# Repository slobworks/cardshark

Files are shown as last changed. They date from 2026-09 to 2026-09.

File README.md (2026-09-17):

cardshark_front
cardshark_back png
<b>Update 9/17/26:</b> Big gaggle of minor changes all over. Bigger, better and cleaner PCB art on the front. Changed all those pesky 0603 0.1uF capacitors to 0805 to make them slightly less fiddly. Had to do some moderate rerouting to compensate - hopefully the 40MHz operation is not adversely affected.

CARDSHARK Tiburon v1.1 - MIT-Licensed, Open-Source Cirrus Logic CL-GD543x Based VLB VGA Card

As it says on the package. This VGA card for the VESA Local Bus supports a maximum memory size of 2MB, using traditional multiple-CAS FPM 256Kx16 SOJ memory. 70ns or faster memory is recommended, as is a CL-GD5434 chip for the fastest speed and least confusing build.
Created using KiCAD 8.0, updated for 10.0 (a thousand apologies if this breaks your older version!)

Features:
- Four layer PCB with cautiously laid ground pours, and judicious usage of stitching vias
- Beefy dedicated regulator providing analog DAC power, for further improved picture quality
- 2MB FPM memory with 64-bit data bus for CL-GD5434
- Compatible with CL-GD5430 and CL-GD5434
- Uses a 27C256-compatible UV PROM or EPROM chip for the BIOS
- Supports 40MHz VLB bus on motherboards that can actually handle that
- Mercifully short mode-switch delays on LCD monitors, unlike most vintage VGA chipsets (a Cirrus quality)
- Features my own hand-drawn artwork on back of board

Release History:
- Tiburon v1.1: Tons o' minor tweaks: bigger, better and cleaner PCB art on the front. Moved BIOS socket so I can reduce the ominous kink in the RGB traces. More forgiving 0805(2012 metric) footprints for the 0.1uF capacitors; you can still fit 0603s to them though. Moved some stuff around to try to get shorter ground loop paths when possible.
- Tiburon v1.0: First proper release.
- Tiburon Take 3 (internal): FINALLY we have a properly working VLB card... so long as you only use a GD5434 and 2MB of memory. One of the RAS lines got screwed, which gets overridden anyway when a GD5434 is used. Also some really minor bugs (wrong resistor values in a couple spots, easily fixed). At least it sure looks nice assembled, and so long as it's given a GD5434 with 2MB, it's a monster (of the good kind).
- Take 2 (internal): Almost worked. Major bugs all over the place. Barely functional.
- 0.1b: Major overhaul. Relaid everything, redid a lot of stuff that was broken and didn't work (if the previous version wasted your money... sorry! I feel like a prize horse's arse for uploading something so broken, as it is!)

Known Issues:
- Hand-soldering that PQFP-208 chip with all those thin little pins is a nightmare, even with hot air
- While generally very good, Mode 13h and EGA image quality isn't 100% perfect on LCD. Some extremely faint vertical lines, though generally much less pronounced than on extant cards; you will probably want to play with your RetroTINK's timings a bit (these seem to be timing related and not noise, as they are not visible at all in SVGA modes)
- EDO is ONLY supported on CL-GD5434-J-QC, but even then it does not improve performance at all. *NO* other versions support EDO, so don't waste money ordering EDO SOJ chips

Bill of Materials: (All passive parts are 0805/2012 metric unless otherwise indicated)
- 1x Cirrus Logic CL-GD5430 or CL-GD5434 PQFP-208 chip (watch out for fakes - they're everywhere)
- 1x SOIC-14 (3.9mm x 8.7mm P1.27mm) SN74F260DR or directly compatible part
- At least 2x, but up to 4x 256Kx16 dual-CAS Fast Page Mode (*NOT* EDO) SOJ-40 DRAM memory
- 1x 78M05 5V DPAK regulator (LF50 is compatible)
- 1x 14.318MHz DIP-14 CXO 4-pin through-hole oscillator
- 1x MMBT3904 SOT-23 NPN transistor
- 1x TL431DBZ SOT-23 programmable shunt reference
- 3x 11 ohm @ 100MHz ferrite beads (for RGB signals)
- 3x 100+ ohm @ 100MHz ferrite beads (for power rails)
- 2x 1x2 2.54mm THT pin headers + jumper caps
- 1x 2x3 1.27mm SMD pin header + jumper caps
- 4x 10pF 25/50v MLCC X5R/X7R ceramic capacitor
- 20x 0805(2012 metric) 0.1uF 25/50v MLCC X5R/X7R ceramic capacitor
- 4x 2.2uF 25/50v MLCC X5R/X7R ceramic capacitor
- 6x 10uF 25/50v MLCC X5R/X7R ceramic capacitor
- 1x 5mm 22uF 16V SMD electrolytic capacitor
- 1x 0 ohm SMD resistor (or a short snip of wire)
- 3x 0603(1608 metric) 10 ohm SMD resistors
- 1x 4x0603 33 ohm convex SMD resistor pack
- 2x 0603(1608 metric) 75 ohm SMD resistors
- 1x 4x0603 75 ohm convex SMD resistor pack
- 1x 100 ohm SMD resistor
- 3x 0603(1608 metric) 6.8K SMD resistors
- 2x 4x0603 6.8K ohm convex SMD resistor packs
- 1x 0603(1608 metric) 270-330 ohm SMD resistor, 1% thin film
- 2x 1K SMD resistors
- 1x DSUB-15-HD right angle through hole VGA connector (something akin to this: https://www.digikey.com/en/products/detail/assmann-wsw-components/A-HDF15A-KG-TAXB/1241905)
- 1x DIP-28 socket + 27C256 or compatible PROM/EEPROM/flash ROM chip for BIOS + BIOS file (figure that out yourself)

Provided under the terms of the MIT License.

As you can see I'm a bit of a neophyte when it comes to this GitHub stuff.
Expect this to change as I become more familiar with the platform.

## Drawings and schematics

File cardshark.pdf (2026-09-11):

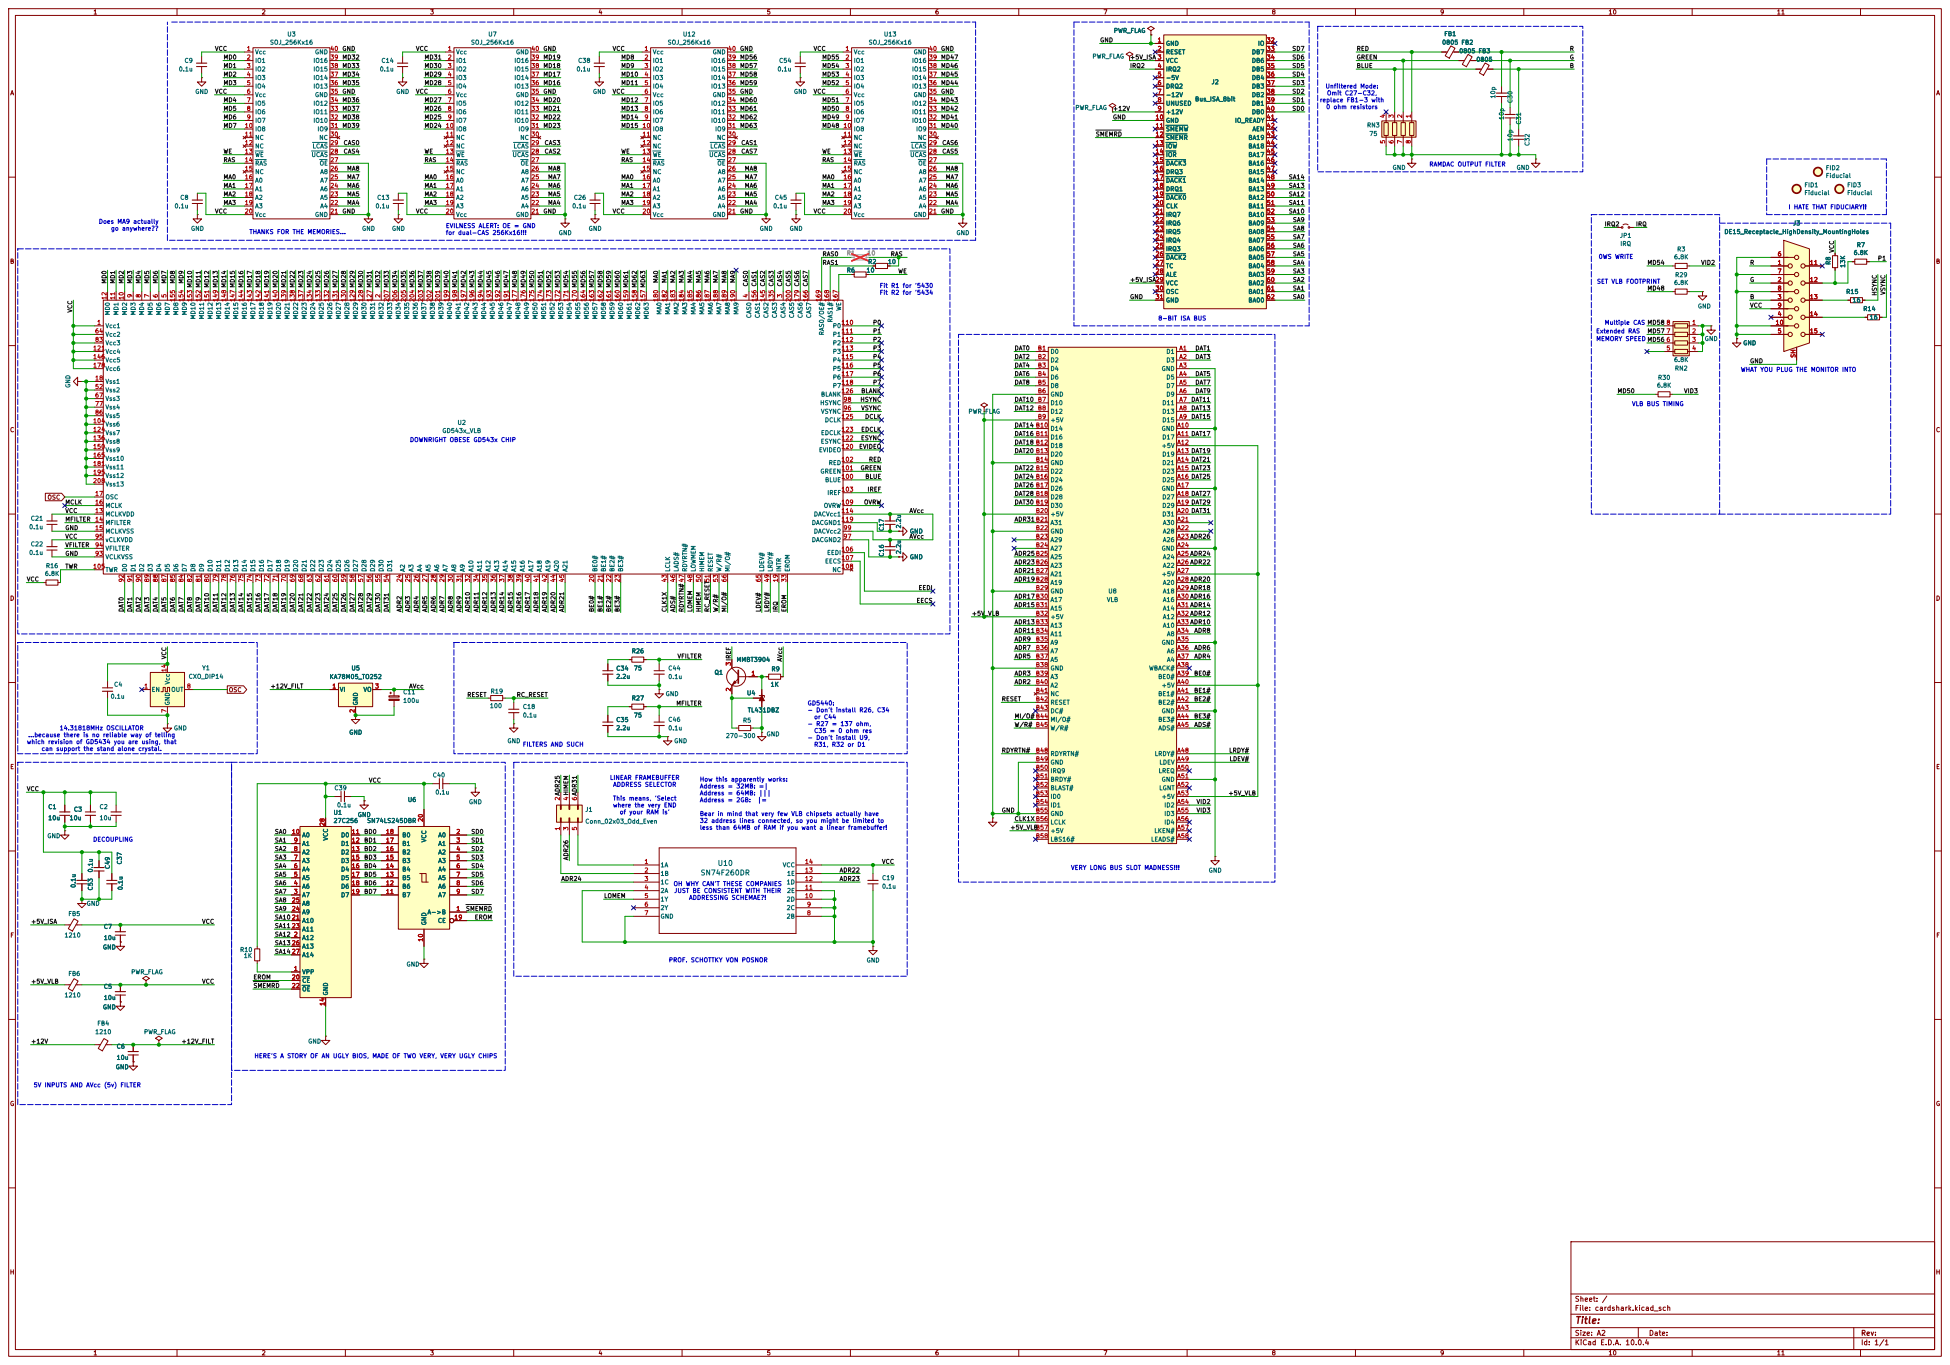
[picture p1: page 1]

PWR_FLAG

VCC
IO8 10 NC 11 NC 12 WE 13 RAS 14 NC 15

J3 DE15_Receptacle_HighDensity_MountingHoles GND

replace FB1-3 with 0 ohm resistors

EVILNESS ALERT: OE = GND
+12V_FILT MD0 +5V_VLB

9 MD2 10 MD1 11 MD0 12 MCLKVDD 13 MFILTER 14 MCLKVSS 15 MCLK 16 OSC 17

3 CAS0
EECS107 NC108 OVRW109 P0110 P1111 P2112 P3113 DACVcc1114 P4115 P5116 P6117 P7118 DACGND1119
Multiple CAS GD5440: - Don't install R26, C34 or C44 - R27 = 137 ohm, C35 = 0 ohm res - Don't install U9,

WHAT YOU PLUG THE MONITOR INTO

A2 B40 NC B41 RESET B42 DC# B43 MI/O# B44 W/R# B45 RDYRTN# B48 GND B49

GND
of your RAM is' FILTERS AND SUCH

ADDRESSING SCHEMAE?! How this apparently works: Address = 32MB: =| Address = 64MB:

This means, 'Select where the very END

Bear in mind that very few VLB chipsets actually have 32 address lines connected, so you might be limited to

less than 64MB of RAM if you want a linear framebuffer!

VERY LONG BUS SLOT MADNESS!!! HERE'S A STORY OF AN UGLY BIOS, MADE OF TWO VERY, VERY UGLY CHIPS

OH WHY CAN'T THESE COMPANIES
JUST BE CONSISTENT WITH THEIR

PROF. SCHOTTKY VON POSNOR

5V INPUTS AND AVcc (5v) FILTER

Size: A2 | Rev:
KiCad E.D.A. 10.0.4 | Id: 1/1

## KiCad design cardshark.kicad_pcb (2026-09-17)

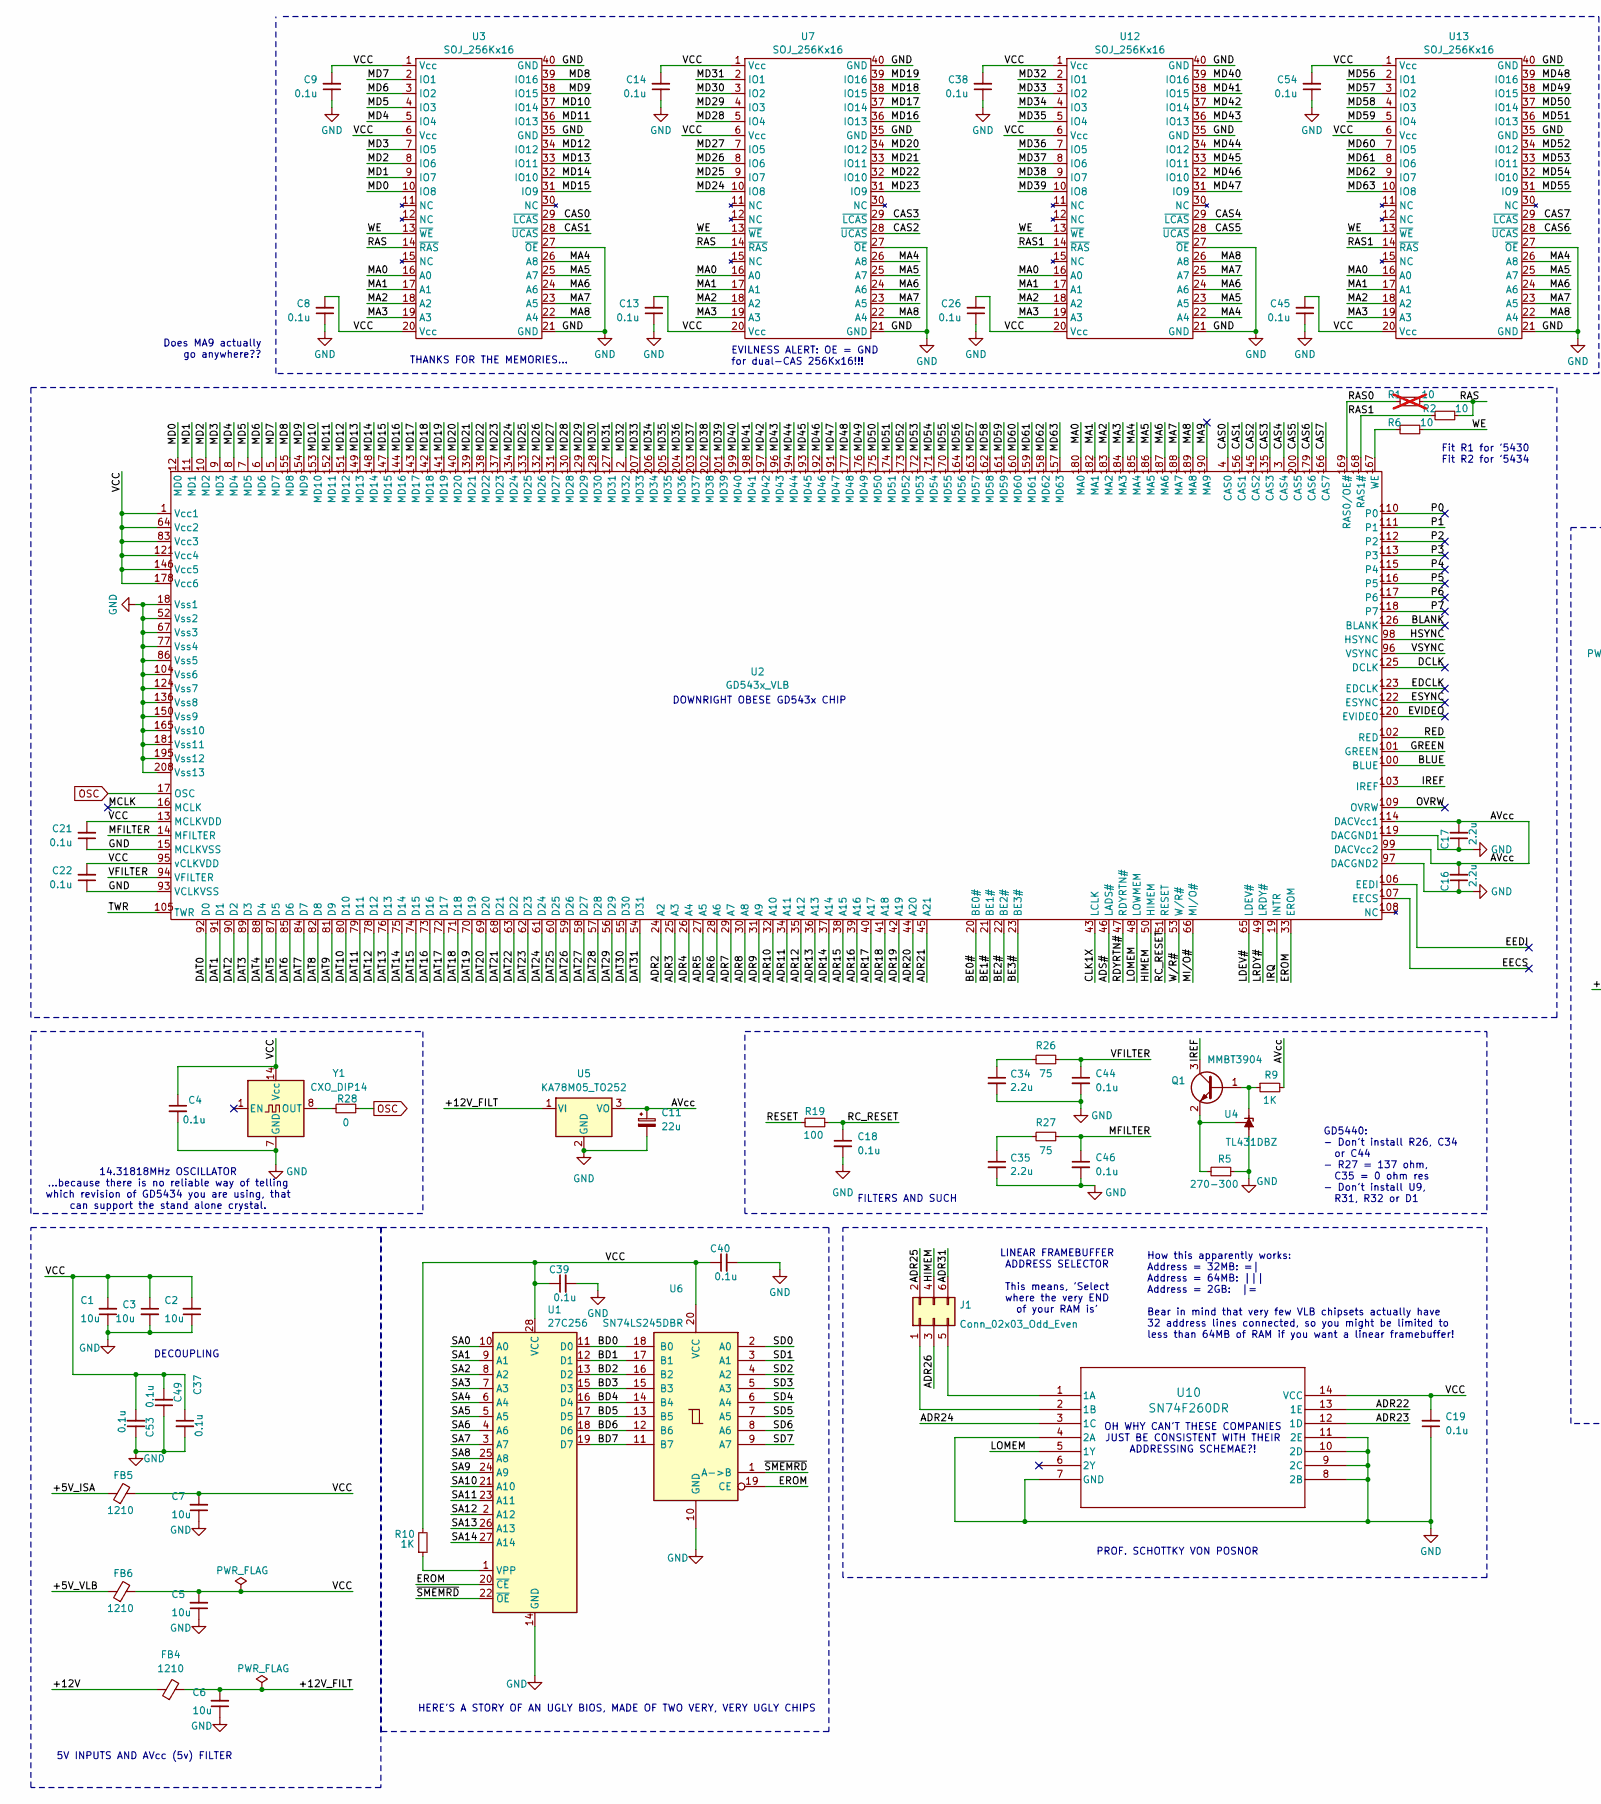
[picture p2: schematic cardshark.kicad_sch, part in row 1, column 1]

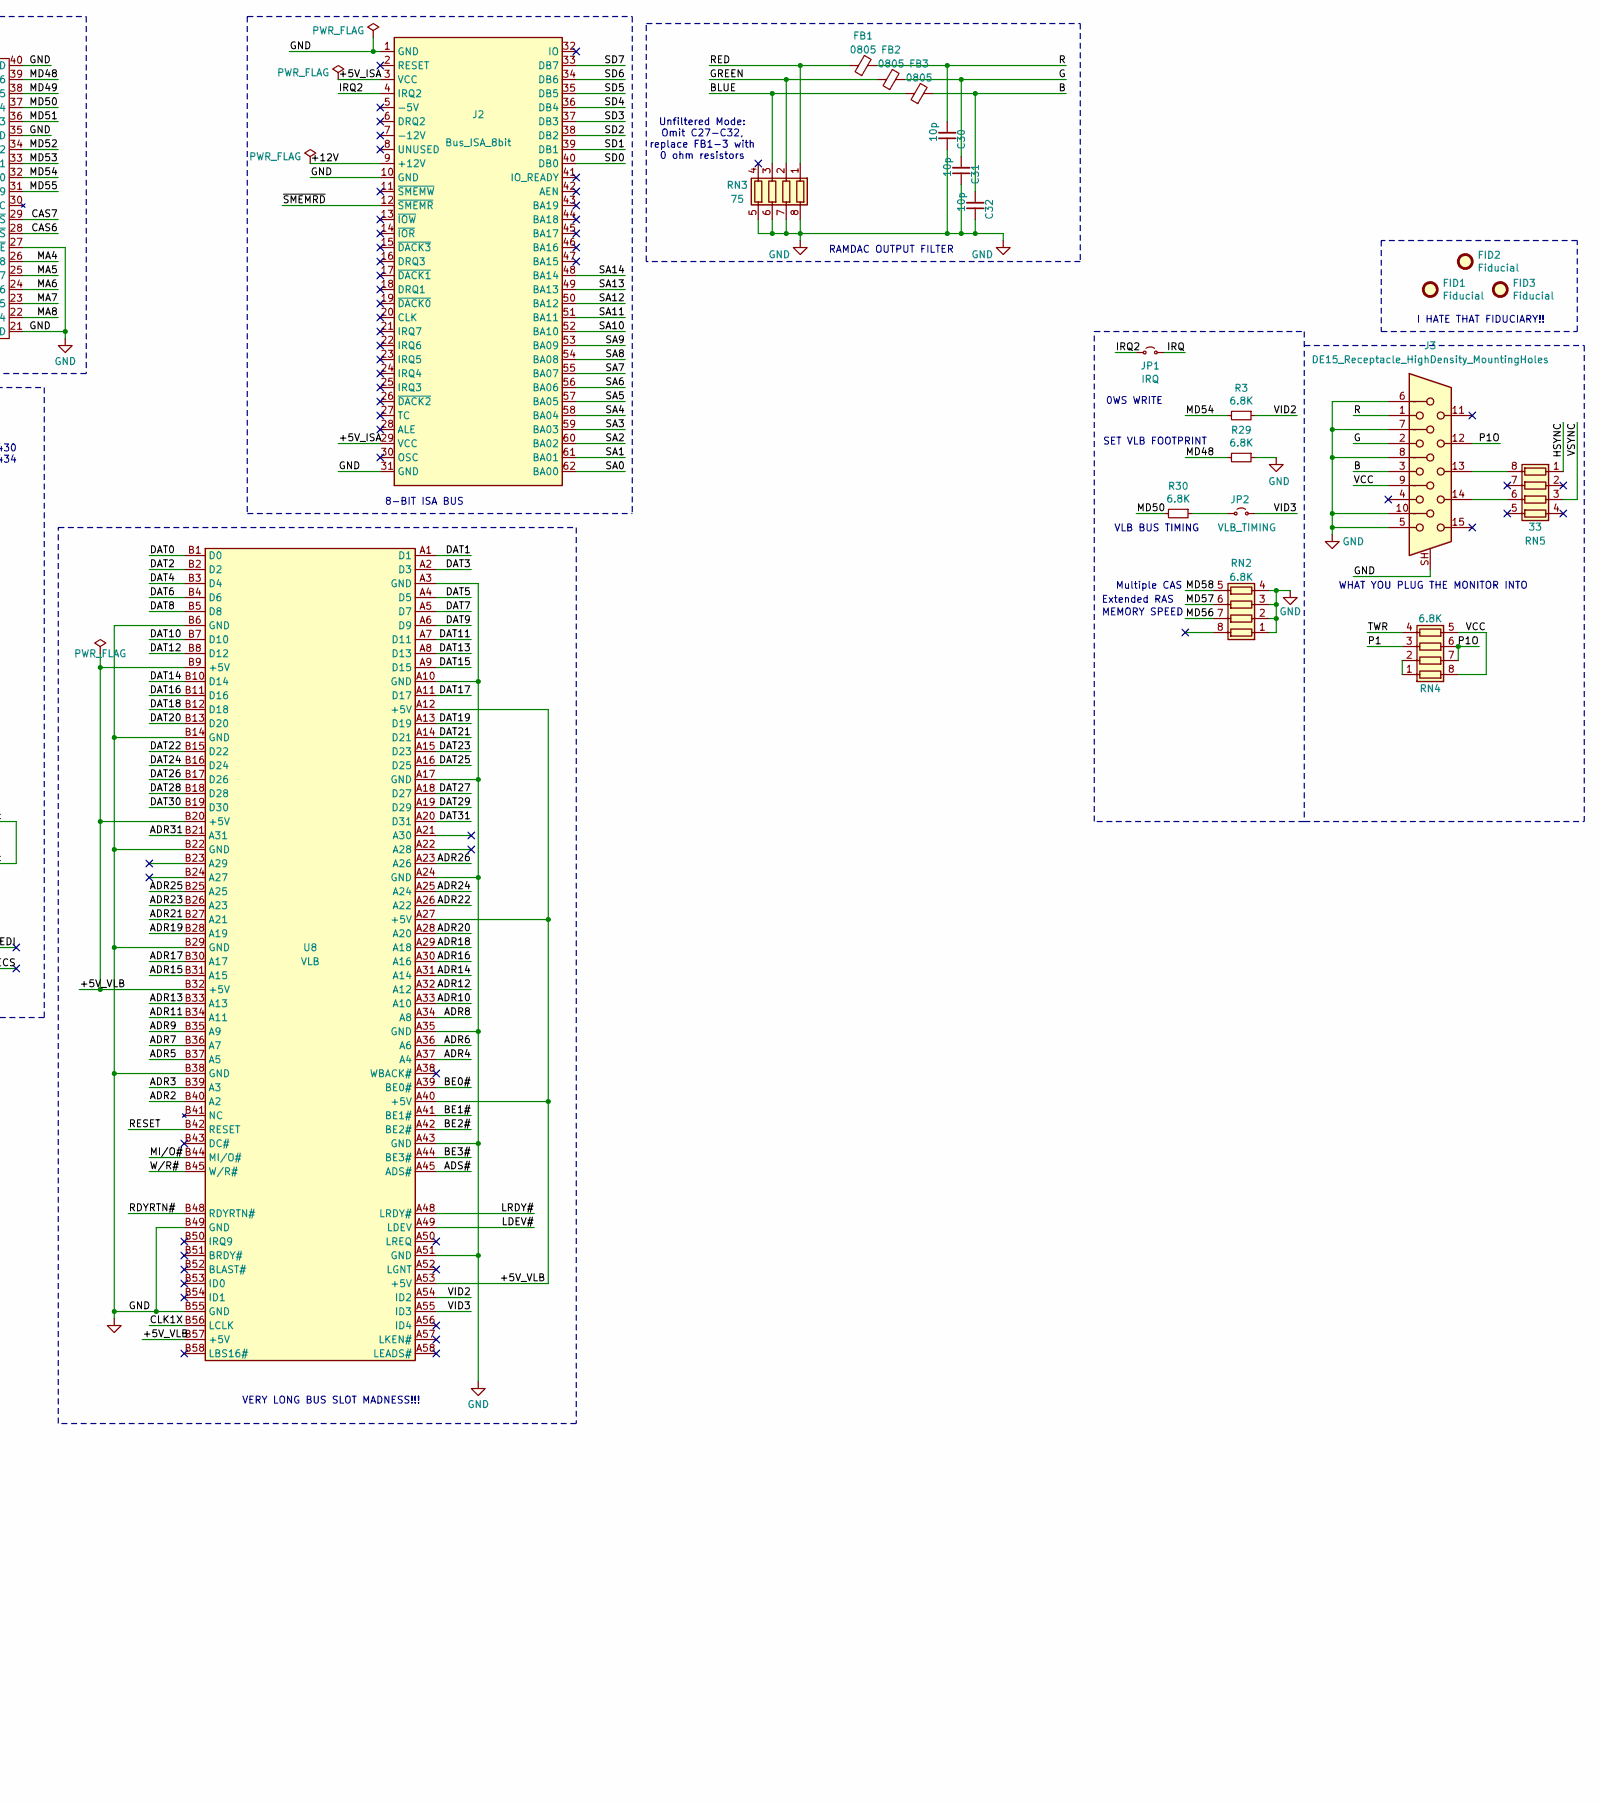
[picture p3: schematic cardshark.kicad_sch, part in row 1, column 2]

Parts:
C1, C2, C3, C5, C6, C7: 10u; C_0805_2012Metric
C4, C8, C9, C13, C14, C18, C19, C21, C22, C26, C37, C38, C39, C40, C44, C45, C46, C49, C53, C54: 0.1u; C_0805_2012Metric
C11: 22u; CP_Elec_5x5.9
C16, C17, C34, C35: 2.2u; C_0805_2012Metric
C30, C31, C32: 10p; C_0805_2012Metric
FB1, FB2, FB3: 0805; L_0805_2012Metric
FB4, FB5, FB6: 1210; L_0805_2012Metric
FID1, FID2, FID3: Fiducial; Fiducial_1mm_Mask2mm
J1: Conn_02x03_Odd_Even; PinHeader_2x03_P1.27mm_Vertical_SMD
J2: Bus_ISA_8bit; ISA
J3: DE15_Receptacle_HighDensity_MountingHoles; DSUB-15-HD
JP1: IRQ; PinHeader_1x02_P2.54mm_Vertical
JP2: VLB_TIMING; PinHeader_1x02_P2.54mm_Vertical
Q1: MMBT3904; SOT-23
R1: 10; R_0603_1608Metric; not fitted
R2, R6: 10; R_0603_1608Metric
R3, R29, R30: 6.8K; R_0603_1608Metric
R5: 270-300; R_0805_2012Metric
R9, R10: 1K; R_0805_2012Metric
R19: 100; R_0805_2012Metric
R26, R27: 75; R_0805_2012Metric
R28: 0; R_0805_2012Metric
RN2, RN4: 6.8K; ResArray_Convex_4x0603
RN3: 75; ResArray_Convex_4x0603
RN5: 33; ResArray_Convex_4x0603
U1: 27C256; DIP-28_W15.24mm_Socket
U2: GD543x_VLB; PQFP-208_28x28mm_P0.5mm
U3, U7, U12, U13: SOJ_256Kx16; SOJ-40_10.16x26.44mm_P1.27mm
U4: TL431DBZ; SOT-23
U5: KA78M05_TO252; TO-252-2
U6: SN74LS245DBR; SSOP-20_5.3x7.2mm_P0.65mm
U8: VLB
U10: SN74F260DR; SOIC-14_3.9x8.7mm_P1.27mm
Y1: CXO_DIP14; Oscillator_SMD_DIP-14

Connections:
/+5V_ISA: FB5.1, J2.3 (VCC), J2.29 (VCC)
/+5V_VLB: FB6.1, U8.A12 (+5V), U8.A27 (+5V), U8.A40 (+5V), U8.A53 (+5V), U8.B9 (+5V), U8.B20 (+5V), U8.B32 (+5V), U8.B57 (+5V)
/+12V: FB4.1, J2.9 (+12V)
/+12V_FILT: C6.2, FB4.2, U5.1 (VI)
/ADR2: U2.24 (A2), U8.B40 (A2)
/ADR3: U2.25 (A3), U8.B39 (A3)
/ADR4: U2.26 (A4), U8.A37 (A4)
/ADR5: U2.27 (A5), U8.B37 (A5)
/ADR6: U2.28 (A6), U8.A36 (A6)
/ADR7: U2.29 (A7), U8.B36 (A7)
/ADR8: U2.30 (A8), U8.A34 (A8)
/ADR9: U2.31 (A9), U8.B35 (A9)
/ADR10: U2.32 (A10), U8.A33 (A10)
/ADR11: U2.34 (A11), U8.B34 (A11)
/ADR12: U2.35 (A12), U8.A32 (A12)
/ADR13: U2.36 (A13), U8.B33 (A13)
/ADR14: U2.37 (A14), U8.A31 (A14)
/ADR15: U2.38 (A15), U8.B31 (A15)
/ADR16: U2.39 (A16), U8.A30 (A16)
/ADR17: U2.40 (A17), U8.B30 (A17)
/ADR18: U2.41 (A18), U8.A29 (A18)
/ADR19: U2.42 (A19), U8.B28 (A19)
/ADR20: U2.44 (A20), U8.A28 (A20)
/ADR21: U2.45 (A21), U8.B27 (A21)
/ADR22: U8.A26 (A22), U10.13 (1E)
/ADR23: U8.B26 (A23), U10.12 (1D)
/ADR24: U8.A25 (A24), U10.3 (1C)
/ADR25: J1.2, U8.B25 (A25)
/ADR26: J1.3, U8.A23 (A26)
/ADR31: J1.6, U8.B21 (A31)
/ADS#: U2.46 (LADS#), U8.A45 (ADS#)
/AVcc: C11.1, C16.2, C17.2, R9.2, U2.99 (DACVcc2), U2.114 (DACVcc1), U5.3 (VO)
/B: C32.2, FB3.2, J3.3
/BD0: U1.11 (D0), U6.18 (B0)
/BD1: U1.12 (D1), U6.17 (B1)
/BD2: U1.13 (D2), U6.16 (B2)
/BD3: U1.15 (D3), U6.15 (B3)
/BD4: U1.16 (D4), U6.14 (B4)
/BD5: U1.17 (D5), U6.13 (B5)
/BD6: U1.18 (D6), U6.12 (B6)
/BD7: U1.19 (D7), U6.11 (B7)
/BE0#: U2.20 (BE0#), U8.A39 (BE0#)
/BE1#: U2.21 (BE1#), U8.A41 (BE1#)
/BE2#: U2.22 (BE2#), U8.A42 (BE2#)
/BE3#: U2.23 (BE3#), U8.A44 (BE3#)
/BLANK: U2.126 (BLANK)
/BLUE: FB3.1, RN3.3 (R3.1), U2.100 (BLUE)
/CAS0: U2.4 (CAS0), U3.29 (~LCAS)
/CAS1: U2.156 (CAS1), U3.28 (~UCAS)
/CAS2: U2.145 (CAS2), U7.28 (~UCAS)
/CAS3: U2.135 (CAS3), U7.29 (~LCAS)
/CAS4: U2.3 (CAS4), U12.29 (~LCAS)
/CAS5: U2.200 (CAS5), U12.28 (~UCAS)
/CAS6: U2.179 (CAS6), U13.28 (~UCAS)
/CAS7: U2.166 (CAS7), U13.29 (~LCAS)
/CLK1X: U2.43 (LCLK), U8.B56 (LCLK)
/DAT0: U2.92 (D0), U8.B1 (D0)
/DAT1: U2.91 (D1), U8.A1 (D1)
/DAT2: U2.90 (D2), U8.B2 (D2)
/DAT3: U2.89 (D3), U8.A2 (D3)
/DAT4: U2.88 (D4), U8.B3 (D4)
/DAT5: U2.87 (D5), U8.A4 (D5)
/DAT6: U2.85 (D6), U8.B4 (D6)
/DAT7: U2.84 (D7), U8.A5 (D7)
/DAT8: U2.82 (D8), U8.B5 (D8)
/DAT9: U2.81 (D9), U8.A6 (D9)
/DAT10: U2.80 (D10), U8.B7 (D10)
/DAT11: U2.79 (D11), U8.A7 (D11)
/DAT12: U2.78 (D12), U8.B8 (D12)
/DAT13: U2.76 (D13), U8.A8 (D13)
/DAT14: U2.75 (D14), U8.B10 (D14)
/DAT15: U2.74 (D15), U8.A9 (D15)
/DAT16: U2.73 (D16), U8.B11 (D16)
/DAT17: U2.72 (D17), U8.A11 (D17)
/DAT18: U2.71 (D18), U8.B12 (D18)
/DAT19: U2.70 (D19), U8.A13 (D19)
/DAT20: U2.69 (D20), U8.B13 (D20)
/DAT21: U2.68 (D21), U8.A14 (D21)
/DAT22: U2.63 (D22), U8.B15 (D22)
/DAT23: U2.62 (D23), U8.A15 (D23)
/DAT24: U2.61 (D24), U8.B16 (D24)
/DAT25: U2.60 (D25), U8.A16 (D25)
/DAT26: U2.59 (D26), U8.B17 (D26)
/DAT27: U2.58 (D27), U8.A18 (D27)
/DAT28: U2.57 (D28), U8.B18 (D28)
/DAT29: U2.56 (D29), U8.A19 (D29)
/DAT30: U2.55 (D30), U8.B19 (D30)
/DAT31: U2.54 (D31), U8.A20 (D31)
/DCLK: U2.125 (DCLK)
/EDCLK: U2.123 (EDCLK)
/EECS: U2.107 (EECS)
/EEDI: U2.106 (EEDI)
/EROM: U1.20 (~CE), U2.33 (EROM), U6.19 (CE)
/ESYNC: U2.122 (ESYNC)
/EVIDEO: U2.120 (EVIDEO)
/G: C31.2, FB2.2, J3.2
/GREEN: FB2.1, RN3.2 (R2.1), U2.101 (GREEN)
/HIMEM: J1.4, U2.50 (HIMEM)
/HSYNC: RN5.1 (R1.1), U2.98 (HSYNC)
/IREF: Q1.3 (C), U2.103 (IREF)
/IRQ: JP1.2 (B), U2.19 (INTR)
/IRQ2: J2.4 (IRQ2), JP1.1 (A)
/LDEV#: U2.65 (LDEV#), U8.A49 (LDEV)
/LOMEM: U2.48 (LOWMEM), U10.5 (1Y)
/LRDY#: U2.49 (LRDY#), U8.A48 (LRDY#)
/MA0: U2.180 (MA0), U3.16 (A0), U7.16 (A0), U12.16 (A0), U13.16 (A0)
/MA1: U2.182 (MA1), U3.17 (A1), U7.17 (A1), U12.17 (A1), U13.17 (A1)
/MA2: U2.183 (MA2), U3.18 (A2), U7.18 (A2), U12.18 (A2), U13.18 (A2)
/MA3: U2.184 (MA3), U3.19 (A3), U7.19 (A3), U12.19 (A3), U13.19 (A3)
/MA4: U2.185 (MA4), U3.26 (A8), U7.26 (A8), U12.22 (A4), U13.26 (A8)
/MA5: U2.186 (MA5), U3.25 (A7), U7.25 (A7), U12.23 (A5), U13.25 (A7)
/MA6: U2.187 (MA6), U3.24 (A6), U7.24 (A6), U12.24 (A6), U13.24 (A6)
/MA7: U2.188 (MA7), U3.23 (A5), U7.23 (A5), U12.25 (A7), U13.23 (A5)
/MA8: U2.189 (MA8), U3.22 (A4), U7.22 (A4), U12.26 (A8), U13.22 (A4)
/MA9: U2.190 (MA9)
/MCLK: U2.16 (MCLK)
/MD0: U2.12 (MD0), U3.10 (IO8)
/MD1: U2.11 (MD1), U3.9 (IO7)
/MD2: U2.10 (MD2), U3.8 (IO6)
/MD3: U2.9 (MD3), U3.7 (IO5)
/MD4: U2.8 (MD4), U3.5 (IO4)
/MD5: U2.7 (MD5), U3.4 (IO3)
/MD6: U2.6 (MD6), U3.3 (IO2)
/MD7: U2.5 (MD7), U3.2 (IO1)
/MD8: U2.155 (MD8), U3.39 (IO16)
/MD9: U2.154 (MD9), U3.38 (IO15)
/MD10: U2.153 (MD10), U3.37 (IO14)
/MD11: U2.152 (MD11), U3.36 (IO13)
/MD12: U2.151 (MD12), U3.34 (IO12)
/MD13: U2.149 (MD13), U3.33 (IO11)
/MD14: U2.148 (MD14), U3.32 (IO10)
/MD15: U2.147 (MD15), U3.31 (IO9)
/MD16: U2.144 (MD16), U7.36 (IO13)
/MD17: U2.143 (MD17), U7.37 (IO14)
/MD18: U2.142 (MD18), U7.38 (IO15)
/MD19: U2.141 (MD19), U7.39 (IO16)
/MD20: U2.140 (MD20), U7.34 (IO12)
/MD21: U2.139 (MD21), U7.33 (IO11)
/MD22: U2.138 (MD22), U7.32 (IO10)
/MD23: U2.137 (MD23), U7.31 (IO9)
/MD24: U2.134 (MD24), U7.10 (IO8)
/MD25: U2.133 (MD25), U7.9 (IO7)
/MD26: U2.132 (MD26), U7.8 (IO6)
/MD27: U2.131 (MD27), U7.7 (IO5)
/MD28: U2.130 (MD28), U7.5 (IO4)
/MD29: U2.129 (MD29), U7.4 (IO3)
/MD30: U2.128 (MD30), U7.3 (IO2)
/MD31: U2.127 (MD31), U7.2 (IO1)
/MD32: U2.2 (MD32), U12.2 (IO1)
/MD33: U2.207 (MD33), U12.3 (IO2)
/MD34: U2.206 (MD34), U12.4 (IO3)
/MD35: U2.205 (MD35), U12.5 (IO4)
/MD36: U2.204 (MD36), U12.7 (IO5)
/MD37: U2.203 (MD37), U12.8 (IO6)
/MD38: U2.202 (MD38), U12.9 (IO7)
/MD39: U2.201 (MD39), U12.10 (IO8)
/MD40: U2.199 (MD40), U12.39 (IO16)
/MD41: U2.198 (MD41), U12.38 (IO15)
/MD42: U2.197 (MD42), U12.37 (IO14)
/MD43: U2.196 (MD43), U12.36 (IO13)
/MD44: U2.194 (MD44), U12.34 (IO12)
/MD45: U2.193 (MD45), U12.33 (IO11)
/MD46: U2.192 (MD46), U12.32 (IO10)
/MD47: U2.191 (MD47), U12.31 (IO9)
/MD48: R29.2, U2.177 (MD48), U13.39 (IO16)
/MD49: U2.176 (MD49), U13.38 (IO15)
/MD50: R30.2, U2.175 (MD50), U13.37 (IO14)
/MD51: U2.174 (MD51), U13.36 (IO13)
/MD52: U2.173 (MD52), U13.34 (IO12)
/MD53: U2.172 (MD53), U13.33 (IO11)
/MD54: R3.2, U2.171 (MD54), U13.32 (IO10)
/MD55: U2.170 (MD55), U13.31 (IO9)
/MD56: RN2.7 (R2.2), U2.164 (MD56), U13.2 (IO1)
/MD57: RN2.6 (R3.2), U2.163 (MD57), U13.3 (IO2)
/MD58: RN2.5 (R4.2), U2.162 (MD58), U13.4 (IO3)
/MD59: U2.161 (MD59), U13.5 (IO4)
/MD60: U2.160 (MD60), U13.7 (IO5)
/MD61: U2.159 (MD61), U13.8 (IO6)
/MD62: U2.158 (MD62), U13.9 (IO7)
/MD63: U2.157 (MD63), U13.10 (IO8)
/MFILTER: C46.1, R27.1, U2.14 (MFILTER)
/MI/O#: U2.66 (MI/O#), U8.B44 (MI/O#)
/OVRW: U2.109 (OVRW)
/P0: U2.110 (P0)
/P1: RN4.3 (R3.1), U2.111 (P1)
/P1O: J3.12, RN4.6 (R3.2), RN4.7 (R2.2)
/P2: U2.112 (P2)
/P3: U2.113 (P3)
/P4: U2.115 (P4)
/P5: U2.116 (P5)
/P6: U2.117 (P6)
/P7: U2.118 (P7)
/R: C30.2, FB1.2, J3.1
/RAS: R1.1, R2.1, U3.14 (~RAS), U7.14 (~RAS)
/RAS0: R1.2, U2.169 (RAS0/OE#)
/RAS1: R2.2, U2.168 (RAS1#), U12.14 (~RAS), U13.14 (~RAS)
/RC_RESET: C18.1, R19.1, U2.51 (RESET)
/RDYRTN#: U2.47 (RDYRTN#), U8.B48 (RDYRTN#)
/RED: FB1.1, RN3.1 (R1.1), U2.102 (RED)
/RESET: R19.2, U8.B42 (RESET)
/SA0: J2.62 (BA00), U1.10 (A0)
/SA1: J2.61 (BA01), U1.9 (A1)
/SA2: J2.60 (BA02), U1.8 (A2)
/SA3: J2.59 (BA03), U1.7 (A3)
/SA4: J2.58 (BA04), U1.6 (A4)
/SA5: J2.57 (BA05), U1.5 (A5)
/SA6: J2.56 (BA06), U1.4 (A6)
/SA7: J2.55 (BA07), U1.3 (A7)
/SA8: J2.54 (BA08), U1.25 (A8)
/SA9: J2.53 (BA09), U1.24 (A9)
/SA10: J2.52 (BA10), U1.21 (A10)
/SA11: J2.51 (BA11), U1.23 (A11)
/SA12: J2.50 (BA12), U1.2 (A12)
/SA13: J2.49 (BA13), U1.26 (A13)
/SA14: J2.48 (BA14), U1.27 (A14)
/SD0: J2.40 (DB0), U6.2 (A0)
/SD1: J2.39 (DB1), U6.3 (A1)
/SD2: J2.38 (DB2), U6.4 (A2)
/SD3: J2.37 (DB3), U6.5 (A3)
/SD4: J2.36 (DB4), U6.6 (A4)
/SD5: J2.35 (DB5), U6.7 (A5)
/SD6: J2.34 (DB6), U6.8 (A6)
/SD7: J2.33 (DB7), U6.9 (A7)
/TWR: RN4.4 (R4.1), U2.105 (TWR)
/VCC: C1.2, C2.2, C3.1, C4.1, C5.2, C7.2, C8.2, C9.2, C13.2, C14.2, C19.2, C21.2, C22.2, C26.2, C37.1, C38.2, C39.1, C40.1, C45.2, C49.2, C53.2, C54.2, FB5.2, FB6.2, J3.9, R10.2, RN4.5 (R4.2), RN4.8 (R1.2), U1.28 (VCC), U2.1 (Vcc1), U2.13 (MCLKVDD), U2.64 (Vcc2), U2.83 (Vcc3), U2.95 (vCLKVDD), U2.121 (Vcc4), U2.146 (Vcc5), U2.178 (Vcc6), U3.1 (Vcc), U3.6 (Vcc), U3.20 (Vcc), U6.20 (VCC), U7.1 (Vcc), U7.6 (Vcc), U7.20 (Vcc), U10.14 (VCC), U12.1 (Vcc), U12.6 (Vcc), U12.20 (Vcc), U13.1 (Vcc), U13.6 (Vcc), U13.20 (Vcc), Y1.14 (Vcc)
/VFILTER: C44.1, R26.1, U2.94 (VFILTER)
/VID2: R3.1, U8.A54 (ID2)
/VID3: JP2.2 (B), U8.A55 (ID3)
/VSYNC: RN5.3 (R3.1), U2.96 (VSYNC)
/WE: R6.1, U3.13 (~WE), U7.13 (~WE), U12.13 (~WE), U13.13 (~WE)
/W/R#: U2.53 (W/R#), U8.B45 (W/R#)
/~SMEMRD: J2.12 (~SMEMR), U1.22 (~OE), U6.1 (A->B)
GND: C1.1, C2.1, C3.2, C4.2, C5.1, C6.1, C7.1, C8.1, C9.1, C11.2, C13.1, C14.1, C16.1, C17.1, C18.2, C19.1, C21.1, C22.1, C26.1, C30.1, C31.1, C32.1, C34.2, C35.2, C37.2, C38.1, C39.2, C40.2, C44.2, C45.1, C46.2, C49.1, C53.1, C54.1, J2.1 (GND), J2.10 (GND), J2.31 (GND), J3.5, J3.6, J3.7, J3.8, J3.10, J3.SH, R5.1, R29.1, RN2.1 (R1.1), RN2.2 (R2.1), RN2.3 (R3.1), RN2.4 (R4.1), RN3.5 (R4.2), RN3.6 (R3.2), RN3.7 (R2.2), RN3.8 (R1.2), U1.14 (GND), U2.15 (MCLKVSS), U2.18 (Vss1), U2.52 (Vss2), U2.67 (Vss3), U2.77 (Vss4), U2.86 (Vss5), U2.93 (VCLKVSS), U2.97 (DACGND2), U2.104 (Vss6), U2.119 (DACGND1), U2.124 (Vss7), U2.136 (Vss8), U2.150 (Vss9), U2.165 (Vss10), U2.181 (Vss11), U2.195 (Vss12), U2.208 (Vss13), U3.21 (GND), U3.27 (~OE), U3.35 (GND), U3.40 (GND), U4.3 (A), U5.2 (GND), U6.10 (GND), U7.21 (GND), U7.27 (~OE), U7.35 (GND), U7.40 (GND), U8.A3 (GND), U8.A10 (GND), U8.A17 (GND), U8.A24 (GND), U8.A35 (GND), U8.A43 (GND), U8.A51 (GND), U8.B6 (GND), U8.B14 (GND), U8.B22 (GND), U8.B29 (GND), U8.B38 (GND), U8.B49 (GND), U8.B55 (GND), U10.4 (2A), U10.7 (GND), U10.8 (2B), U10.9 (2C), U10.10 (2D), U10.11 (2E), U12.21 (GND), U12.27 (~OE), U12.35 (GND), U12.40 (GND), U13.21 (GND), U13.27 (~OE), U13.35 (GND), U13.40 (GND), Y1.7 (GND)
unnamed: C34.1, R26.2
unnamed: C35.1, R27.2
unnamed: J1.1, U10.2 (1B)
unnamed: J1.5, U10.1 (1A)
unnamed: JP2.1 (A), R30.1
unnamed: Q1.1 (B), R9.1, U4.1 (K)
unnamed: Q1.2 (E), R5.2, U4.2 (REF)
unnamed: RN4.1 (R1.1), RN4.2 (R2.1)
unnamed: J3.13, RN5.8 (R1.2)
unnamed: J3.14, RN5.6 (R3.2)
unnamed: R10.1, U1.1 (VPP)
unnamed: R6.2, U2.167 (WE)
unnamed: R28.2, Y1.8 (OUT)
OSC: R28.1, U2.17 (OSC)

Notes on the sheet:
Unfiltered Mode: Omit C27-C32, replace FB1-3 with 0 ohm resistors
GD5440: - Don't install R26, C34 or C44 - R27 = 137 ohm, C35 = 0 ohm res - Don't install U9, R31, R32 or D1
8-BIT ISA BUS
OH WHY CAN'T THESE COMPANIES JUST BE CONSISTENT WITH THEIR ADDRESSING SCHEMAE?!
HERE'S A STORY OF AN UGLY BIOS, MADE OF TWO VERY, VERY UGLY CHIPS
Multiple CAS
FILTERS AND SUCH
How this apparently works: Address = 32MB: =| Address = 64MB: ||| Address = 2GB: |= Bear in mind that very few VLB chipsets actually have 32 address lines connected, so you might be limited to less than 64MB of RAM if you want a linear framebuffer!
0WS WRITE
VLB BUS TIMING
14.31818MHz OSCILLATOR ...because there is no reliable way of telling which revision of GD5434 you are using, that can support the stand alone crystal.
Fit R1 for '5430 Fit R2 for '5434
Does MA9 actually go anywhere??
THANKS FOR THE MEMORIES...
DOWNRIGHT OBESE GD543x CHIP
VERY LONG BUS SLOT MADNESS!!!
MEMORY SPEED
5V INPUTS AND AVcc (5v) FILTER
SET VLB FOOTPRINT
WHAT YOU PLUG THE MONITOR INTO
LINEAR FRAMEBUFFER ADDRESS SELECTOR This means, 'Select where the very END of your RAM is'
RAMDAC OUTPUT FILTER
I HATE THAT FIDUCIARY!!
Extended RAS
DECOUPLING
PROF. SCHOTTKY VON POSNOR
EVILNESS ALERT: OE = GND for dual-CAS 256Kx16!!!

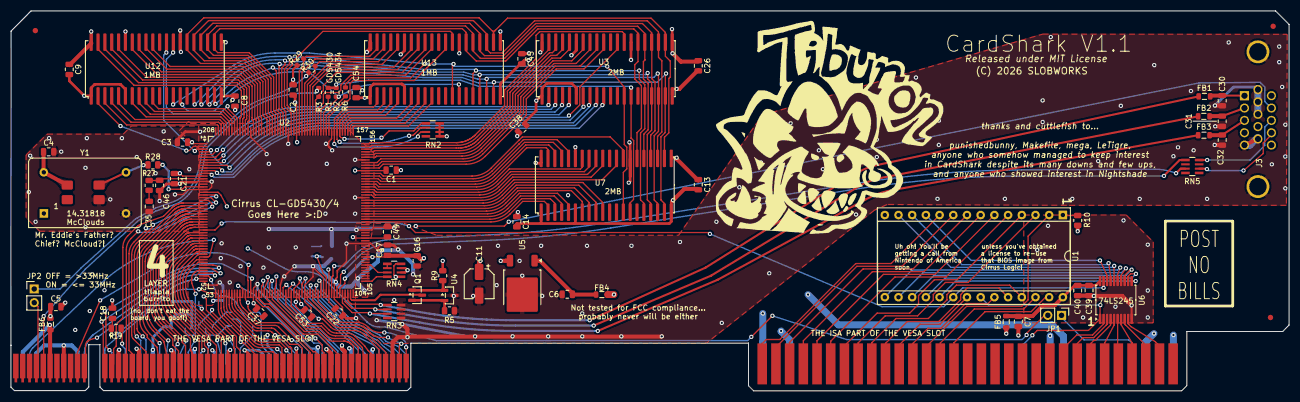
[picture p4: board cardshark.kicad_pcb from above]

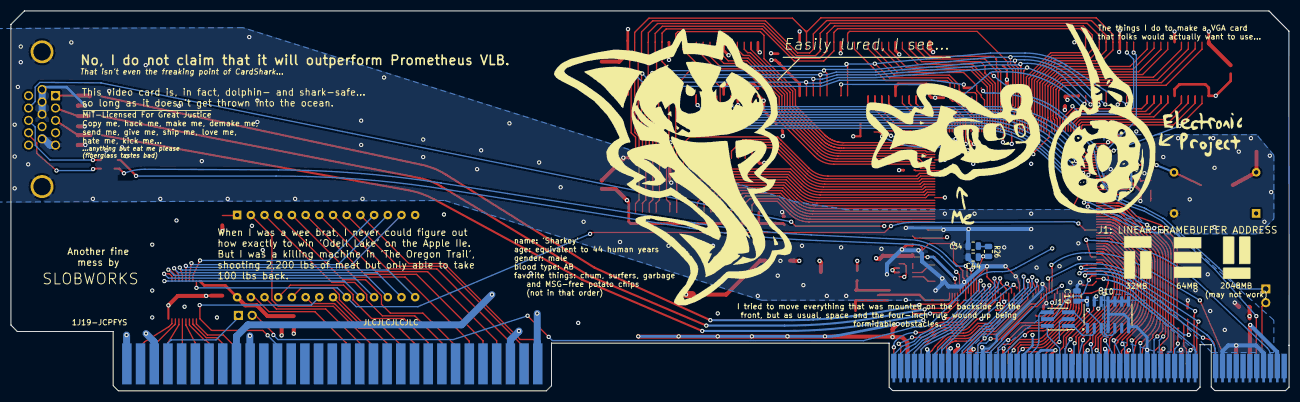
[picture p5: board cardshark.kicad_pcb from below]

Board: 4 copper layers, 237.0 x 70.4 mm, 78 parts (6 on the bottom side), 230 nets.

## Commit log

2025-01-08 Add files via upload
    Naturally I'd forget the CSV BOM... there you go.
2025-01-08 Add files via upload
    A bunch of quick changes
    [cardshark-B_Cu.gbr, cardshark-B_Mask.gbr, cardshark-B_Paste.gbr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]
2025-01-09 Add files via upload
    Cleaned up PCB graphics to make them actually vaguely fabbable
    [cardshark-B_Cu.gbr, cardshark-B_Mask.gbr, cardshark-B_Paste.gbr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]
2025-01-10 Add files via upload
    Hasty bug-fix to a nasty broken PLCC-32 socket problem
    [cardshark-B_Cu.gbr, cardshark-B_Mask.gbr, cardshark-B_Paste.gbr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]
2025-01-19 Add files via upload
    Big bunch'o little minor fixes, no version number change (mostly to clean up libraries and eliminate a bunch of previously silenced ERC warnings)
    [cardshark-B_Cu.gbr, cardshark-B_Mask.gbr, cardshark-B_Paste.gbr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]
2025-09-04 Delete cardshark-B_Cu.gbr
    Deleting crappy broken VLB version files
    [cardshark-B_Cu.gbr]
2025-09-04 Delete cardshark-B_Mask.gbr
    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
    [cardshark-B_Mask.gbr]
2025-09-04 Delete cardshark-B_Paste.gbr
    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
    [cardshark-B_Paste.gbr]
2025-09-04 Delete cardshark-B_Silkscreen.gbr
    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
    [cardshark-B_Silkscreen.gbr]
2025-09-04 Delete cardshark-Edge_Cuts.gbr
    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
    [cardshark-Edge_Cuts.gbr]
2025-09-04 Delete cardshark-F_Cu.gbr
    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
    [cardshark-F_Cu.gbr]
2025-09-04 Delete cardshark-F_Mask.gbr
    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
    [cardshark-F_Mask.gbr]
2025-09-04 Delete cardshark-F_Paste.gbr
    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
    [cardshark-F_Paste.gbr]
2025-09-04 Delete cardshark-F_Silkscreen.gbr
    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
    [cardshark-F_Silkscreen.gbr]
2025-09-04 Delete cardshark-GND_Cu.gbr
    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
    [cardshark-GND_Cu.gbr]
2025-09-04 Delete cardshark-NPTH-drl_map.gbr
    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
    [cardshark-NPTH-drl_map.gbr]
2025-09-04 Delete cardshark-NPTH.drl
    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
    [cardshark-NPTH.drl]
2025-09-04 Delete cardshark-PTH-drl_map.gbr
    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
    [cardshark-PTH-drl_map.gbr]
2025-09-04 Delete cardshark-PTH.drl
    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
    [cardshark-PTH.drl]
2025-09-04 Delete cardshark-Vcc_Cu.gbr
    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
    [cardshark-Vcc_Cu.gbr]
2025-09-04 Delete cardshark-job.gbrjob
    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
    [cardshark-job.gbrjob]
2025-09-04 Delete cardshark-rescue.kicad_sym
    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
2025-09-04 Delete cardshark.bom
    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
2025-09-04 Delete cardshark.kicad_pcb
    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
    [cardshark.kicad_pcb]
2025-09-04 Delete cardshark.kicad_prl
    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
2025-09-04 Delete cardshark.kicad_pro
    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
2025-09-04 Delete cardshark.kicad_sch
    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
    [cardshark.kicad_sch]
2025-09-04 Delete carshark.kicad_prl
    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
2025-09-04 Delete ~cardshark.kicad_pcb.lck
    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
2025-09-04 Delete ~cardshark.kicad_sch.lck
    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
2026-08-28 Clarify dedicated regulator and update release history
    Updated the README to clarify the dedicated regulator feature and improved the description of the internal release history.
2026-08-29 Update README for KiCAD version change
    Updated the README to reflect changes in KiCAD version.
2026-09-11 Add files via upload
    FINALLY uploading the files for the VLB version, after a very long hiatus
    [cardshark-B_Cu.gbr, cardshark-B_Mask.gbr, cardshark-B_Paste.gbr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]
2026-09-11 Update README.md
    Bill of Materials, other stuff I forgot (getting tired)
2026-09-11 Update README.md
    Forgot the DSUB-15 HD connector, oops
2026-09-11 Add feature on LCD monitor mode-switch delays
    Added a feature about short mode-switch delays on LCD monitors.
2026-09-11 Fix typo in README for analog DAC power description
2026-09-17 v1.1 Tweak-Up Release
    LOTS of minor tweaks. Bigger, better and cleaner PCB art on the front. Updated pictures and BOM.
2026-09-17 Add files via upload
    Updated to v1.1. LOTS of minor tweaks all over.
    [cardshark-B_Cu.gbr, cardshark-B_Mask.gbr, cardshark-B_Paste.gbr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]
2026-09-17 Update README.md
    forgot to denote which of those pin headers is SMT and THT

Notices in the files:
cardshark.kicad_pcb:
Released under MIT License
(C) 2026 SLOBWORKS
